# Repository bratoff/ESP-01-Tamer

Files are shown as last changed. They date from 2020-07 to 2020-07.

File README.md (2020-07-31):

# ESP-01-Tamer
Breadboard-friendly breakout, level shift and programming adapter for ESP-01 ESP8266 module.

This little board makes it super easy to use the ESP-8266 ESP-01 board in the Arduino environment.  

The following features are provided:  
- CH340G based USB serial interface  
- Auto control of RST/IO0 for downloading (uses DTR and RTS)  
- Onboard 3.3v regulator  
- Bidirectional 5v/3.3v logic level conversion on Rx, Tx, IO0, IO2  
- Breadboard-friendly breakout of all essential pins  

There are two versions of this board:  
ESP-01_Tamer   - all above features, with a USB A male connector to host  
ESP-01_Tamer-u - all the same features, but with a micro USB female conneector to host  

Common parts list:  
R1-R9 -   10K 0805 size  
R10,R11 - 470 ohm 0805 size  
R12,R13 - 10K 0805 size  
Y1 - 12mhz SMD-3 ceramic resonator  
IC1 - LD117AS33TR SOT223 3.3v 3-terminal regulator  
IC2 - CH340G USB to serial interface  
D1 - B5819W-TP SOD123 Schottky diode  
C1,C4 - 100nf 0805 size  
C2,C3 - 10uf 0805 size  
Q1-Q4 - 2N7002 SOT23  
Q5,Q6 - S8050 SOT23  
JP1 - 2x4 0.1" thru-hole female header  
JP2,JP3 - 1x4 0.1" thru-hole male header  

USB-A version only:  
JP4 - USB A male thru-hole PCB connector  

Micro-USB version only:  
JP4 - 1x1 0.1" thru-hole male header (in case you need the micro USB ID pin)  
J1 - Hirose  ZX62D-B-5PA8 micro USB female surface mount connector  

PC boards are available on OSHpark:  
USB-A:  <https://oshpark.com/shared_projects/sAVimhVZ>  
microUSB: <https://oshpark.com/shared_projects/1ui7zgvW>

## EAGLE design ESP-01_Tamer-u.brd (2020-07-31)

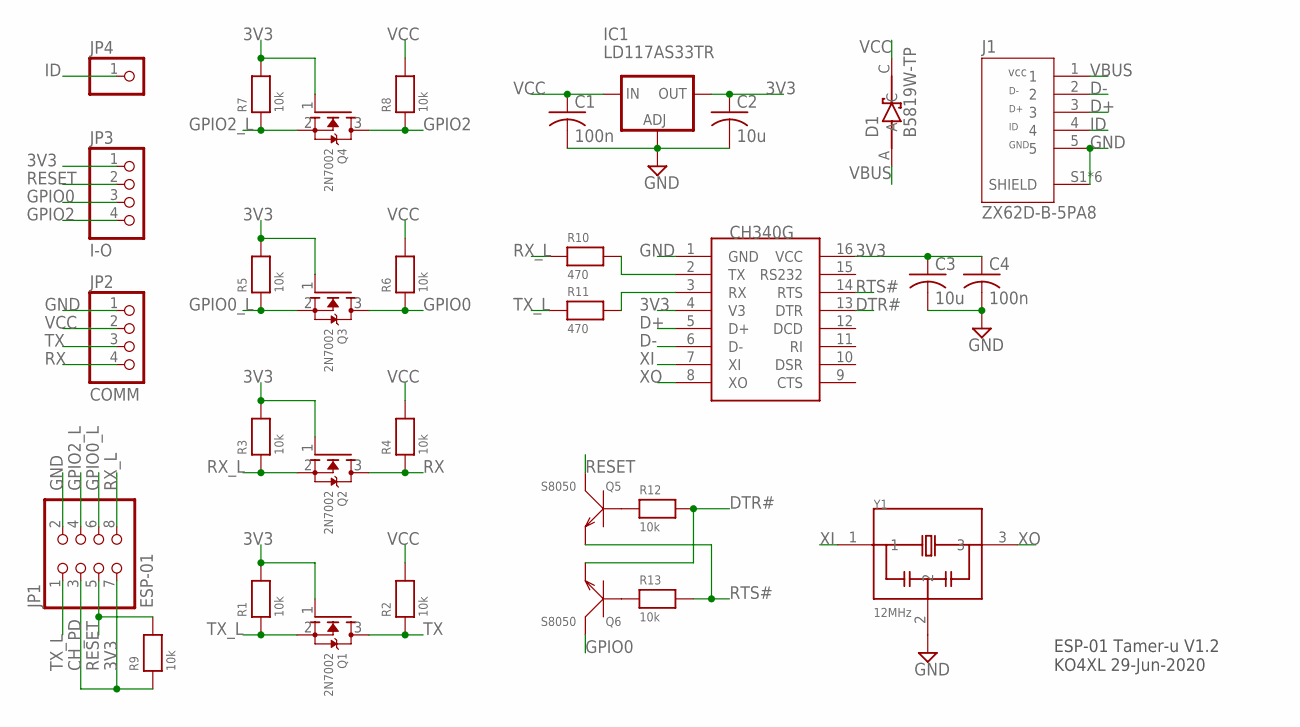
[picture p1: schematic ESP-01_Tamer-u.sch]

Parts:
C1, C4: 100n; C0805K
C2, C3: 10u; C0805K
D1: B5819W-TP; SOD3716X135N
IC1: LD117AS33TR; SOT223
IC2: CH340G; SOIC16
J1: ZX62D-B-5PA8; HIROSE_ZX62D-B-5PA8
JP1: ESP-01; 2X04
JP2: COMM; 1X04_ROUND
JP3: I-O; 1X04_ROUND
JP4: HEADER-1X1ROUND; 1X01_ROUND
Q1, Q2, Q3, Q4: 2N7002; SOT23-WIDE
Q5, Q6: S8050; SOT-23
R1, R2, R3, R4, R5, R6, R7, R8, R9, R12, R13: 10k; 0805_NOTHERMALS
R10, R11: 470; 0805_NOTHERMALS
Y1: 12MHz; OSC_CSTCE8M00G55-R0

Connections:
3V3: C2.1, C3.1, C4.1, IC1.4 (OUT), IC2.4 (V3), IC2.16 (VCC), JP1.3, JP1.7, JP3.1, Q1.1 (G), Q2.1 (G), Q3.1 (G), Q4.1 (G), R1.2, R3.2, R5.2, R7.2, R9.1
D+: IC2.5 (D+), J1.3
D-: IC2.6 (D-), J1.2
DTR#: IC2.13 (DTR), Q6.2 (E), R12.2
GND: C1.2, C2.2, C3.2, C4.2, IC1.1 (ADJ), IC2.1 (GND), J1.5, J1.S1 (SHIELD), J1.S2 (SHIELD), J1.S3 (SHIELD), J1.S4 (SHIELD), J1.S5 (SHIELD), J1.S6 (SHIELD), JP1.2, JP2.1, Y1.2
GPIO0: JP3.3, Q3.3 (D), Q6.3 (C), R6.1
GPIO0_L: JP1.6, Q3.2 (S), R5.1
GPIO2: JP3.4, Q4.3 (D), R8.1
GPIO2_L: JP1.4, Q4.2 (S), R7.1
ID: J1.4, JP4.1
unnamed: Q5.1 (B), R12.1
unnamed: Q6.1 (B), R13.1
unnamed: IC2.2 (TX), R10.2
unnamed: IC2.3 (RX), R11.2
RESET: JP1.5, JP3.2, Q5.3 (C), R9.2
RTS#: IC2.14 (RTS), Q5.2 (E), R13.2
RX: JP2.4, Q2.3 (D), R4.1
RX_L: JP1.8, Q2.2 (S), R3.1, R10.1
TX: JP2.3, Q1.3 (D), R2.1
TX_L: JP1.1, Q1.2 (S), R1.1, R11.1
VBUS: D1.A, J1.1
VCC: C1.1, D1.C, IC1.3 (IN), JP2.2, R2.2, R4.2, R6.2, R8.2
XI: IC2.7 (XI), Y1.1
XO: IC2.8 (XO), Y1.3

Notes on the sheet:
CH_PD
ESP-01 Tamer-u V1.2 KO4XL 29-Jun-2020

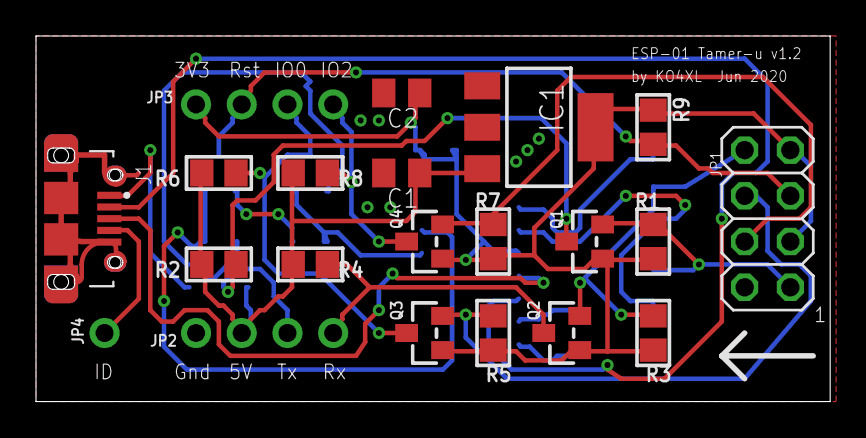
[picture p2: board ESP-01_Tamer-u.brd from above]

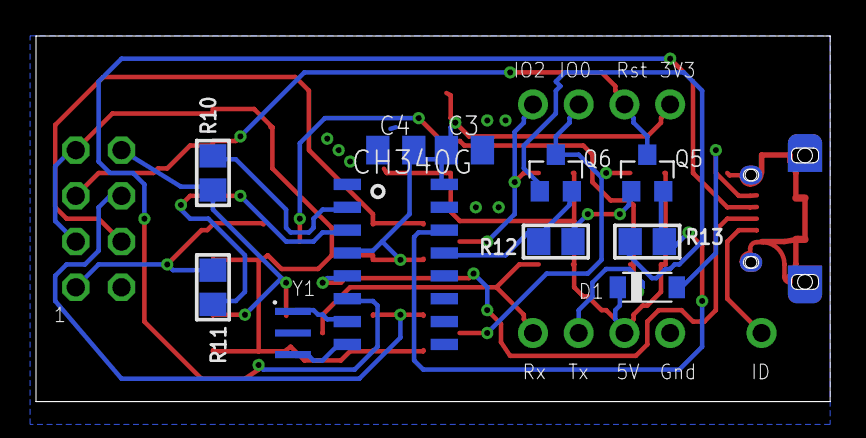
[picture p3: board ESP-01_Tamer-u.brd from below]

Board: 2 copper layers, 44.1 x 20.3 mm, 32 parts (11 on the bottom side), 24 nets.

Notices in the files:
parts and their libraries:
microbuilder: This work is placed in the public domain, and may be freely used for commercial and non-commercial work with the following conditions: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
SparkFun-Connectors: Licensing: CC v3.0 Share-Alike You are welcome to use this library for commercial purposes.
